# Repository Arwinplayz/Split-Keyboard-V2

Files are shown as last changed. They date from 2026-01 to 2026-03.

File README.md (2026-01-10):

# Split-Keyboard V2

I recently got my PCB from JLCPCB but I realised that I had accidentally inverted the holes for the hotswap sockets. This makes it physically impossible for me to actually assembly it properly. Learning from my failures, I decided to make a V2 which would not only fix the socket problem but also allow me to redo/refine some features. That is I want to add a LiPo battery and change the requirement of having both sides plugged in separately to the PC. I already have the parts to build the keyboard so the grant is only for the PCB (and possibly extra stuff such as LiPo battery, resistors, JST PH connectors, etc)

## Planning

I recently got my PCB from JLCPCB but I realised that I had accidentally inverted the holes for the hotswap sockets. This makes it physically impossible for me to actually assembly it properly. (Awkward placement + overlap with other components)

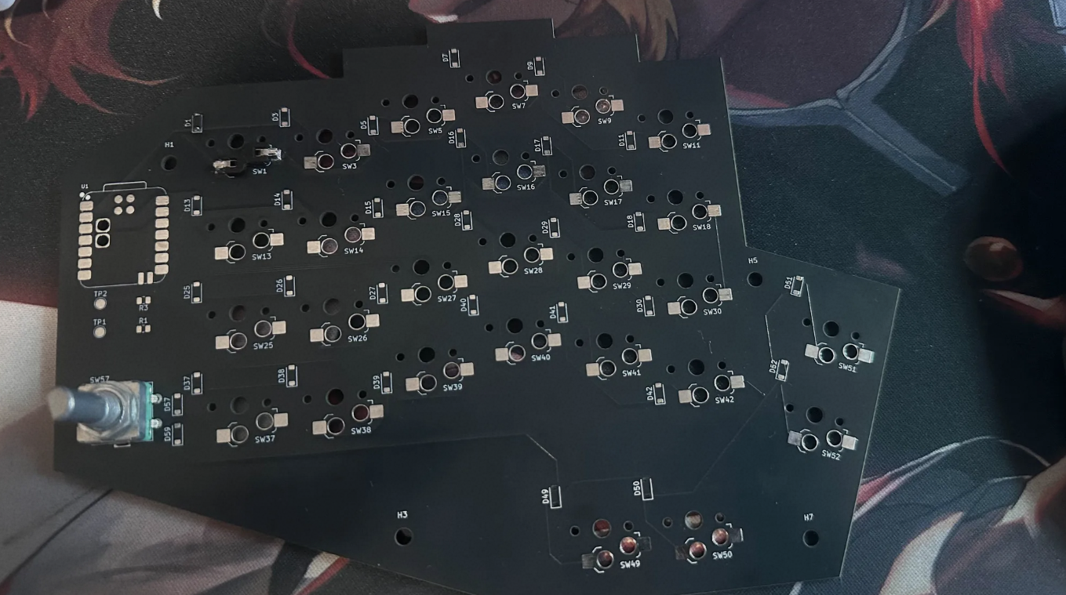
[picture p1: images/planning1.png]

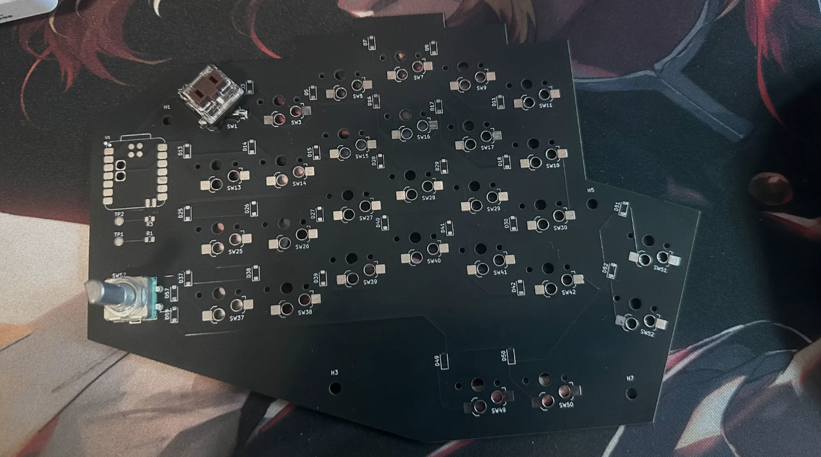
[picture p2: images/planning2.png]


Learning from my failures, I decided to make a V2 which would not only fix the socket problem but also allow me to redo/refine some features. That is I want to add a LiPo battery and change the requirement of having both sides plugged in separately to the PC. I already have the parts to build the keyboard so the grant is only for the PCB (and possibly extra stuff such as LiPo battery, resistors, JST PH connectors, etc)

GOALS:

Fix hotswap socket orientation
Added better connectivity between the split keyboards (Master and Slave RP2040)
Add support for 1s 3.4V LiPo Battery

## Heavily Modified Schematic

So firstly, I realised that to use the master and slave approach, I needed a TRRS which connects the halves via UART. This meant that I needed a UARTTX, UARTRX but all my gpio pins were occupied. After some research I found that the nice!nano v2 was a good choice as it had the same Nordic chip. This allowed for bluetooth connection, a built in linear Li-Po charging circuit which helps avoid clutter. Furthermore, I added a 2 pin JST-PH connector for the Li-Po battery. There is also an RGB LED which will signal green for charged, yellow for 50$, red for low and blue for charging.

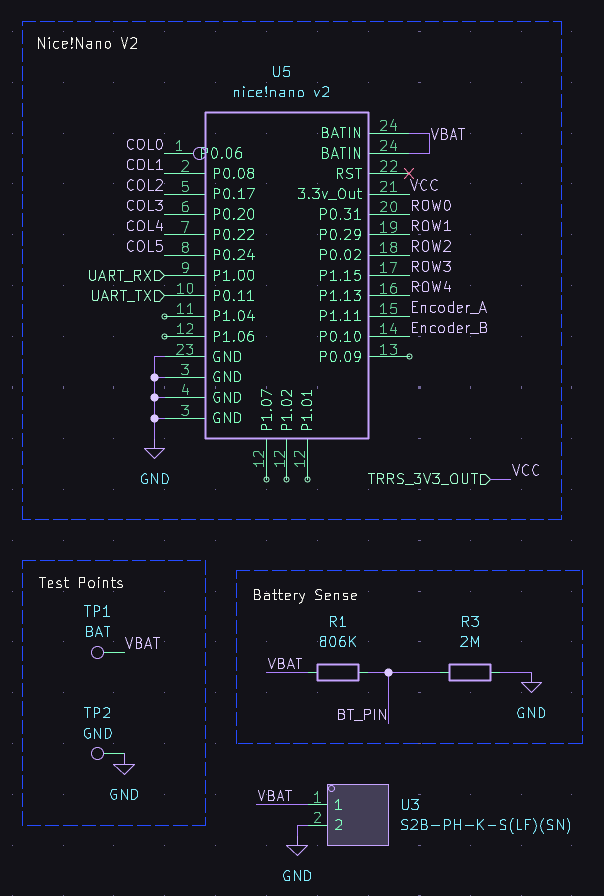
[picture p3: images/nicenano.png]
Nice!nano V2

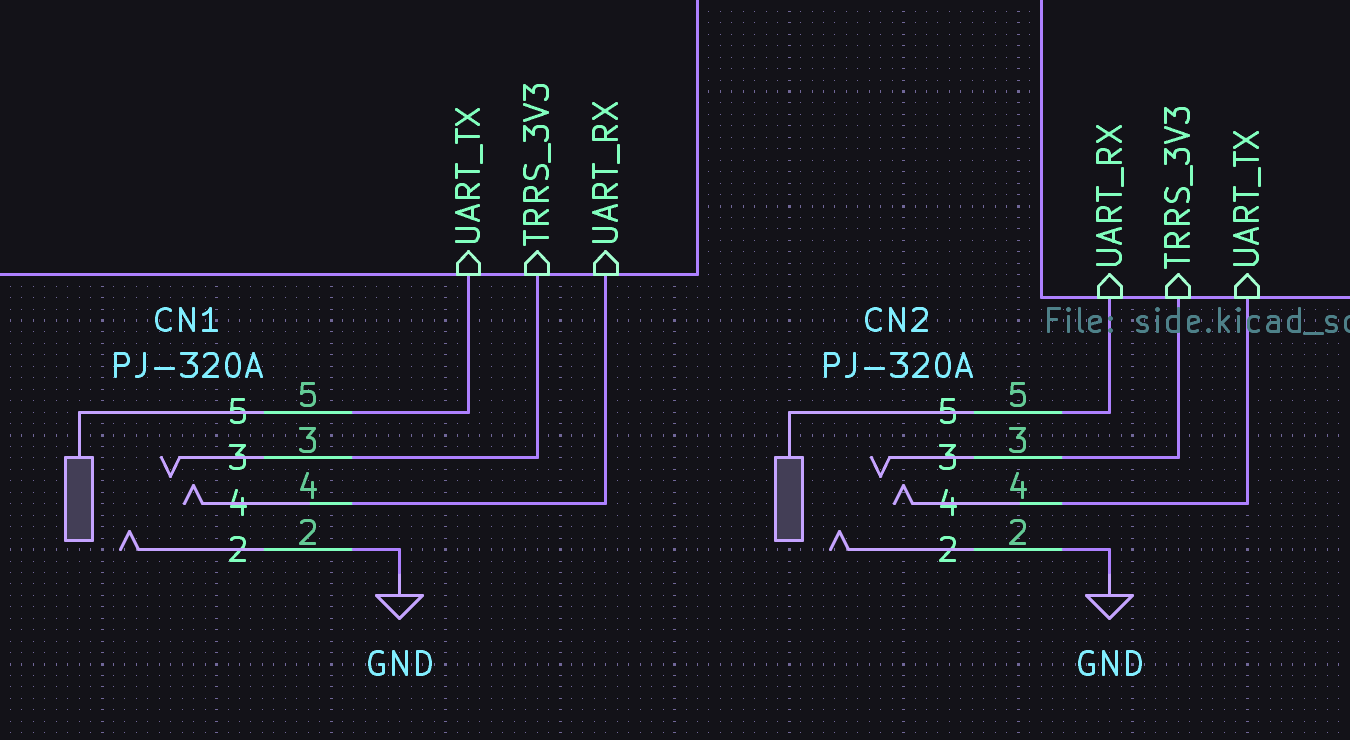
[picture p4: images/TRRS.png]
TRRS

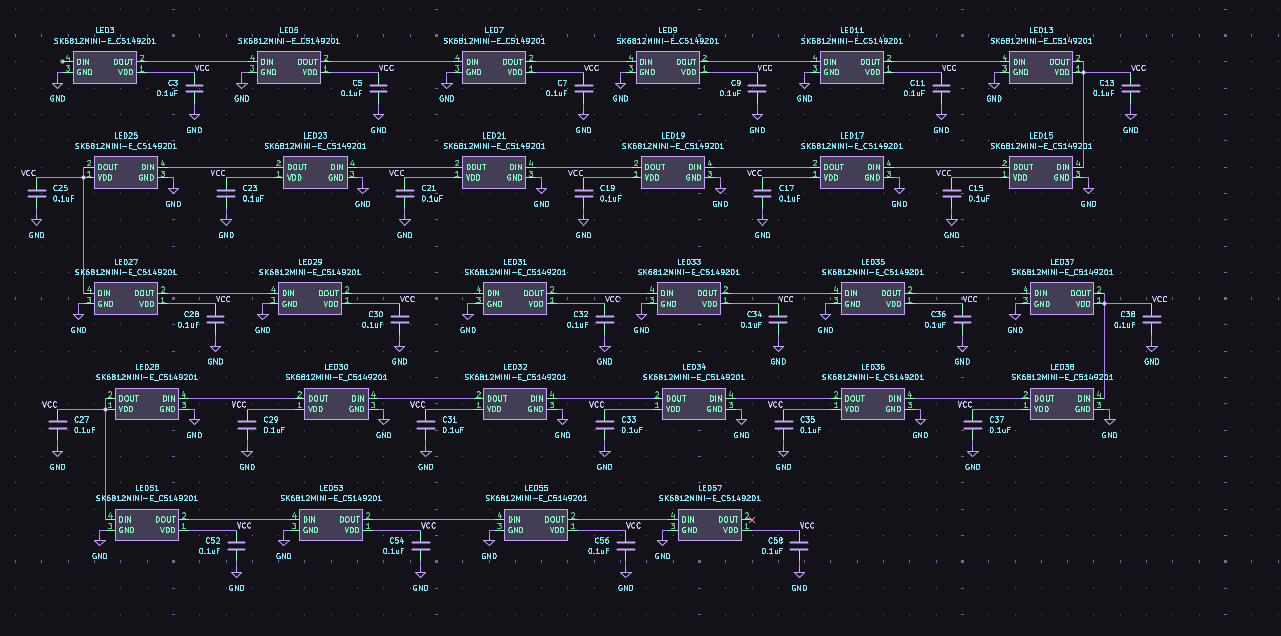
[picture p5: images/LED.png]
LED


## Routed half the PCB

So I managed to route half the PCB now. There were many problems related to footprints as the Nice!Nano doesn't really have a goof publicly available one and so I had to design it myself. Also I added LED lights for every switch and ensured the hotswap sockets were orientated the right way.

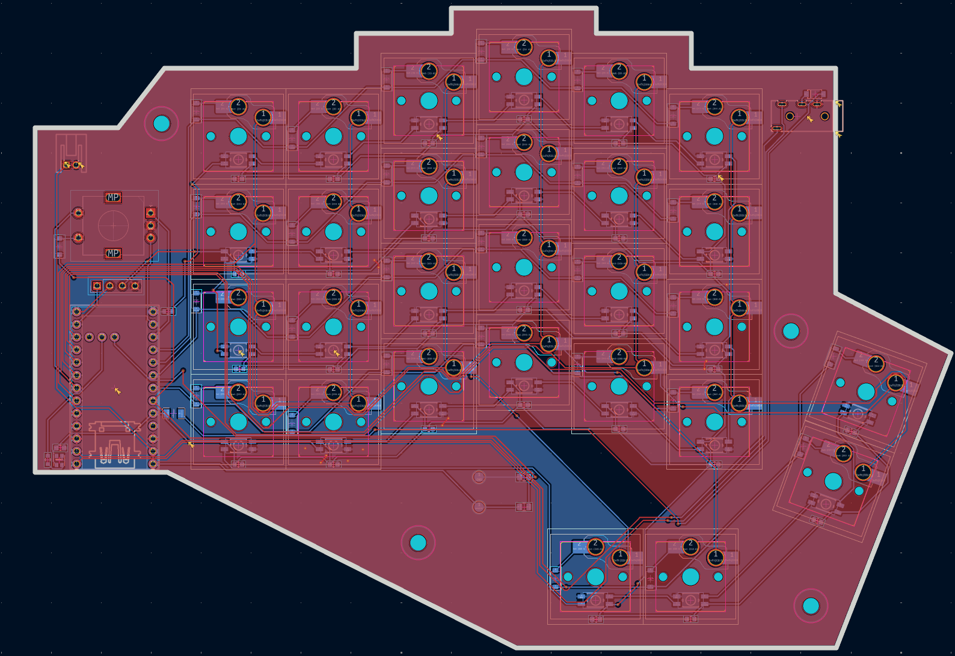
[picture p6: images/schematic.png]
schematic

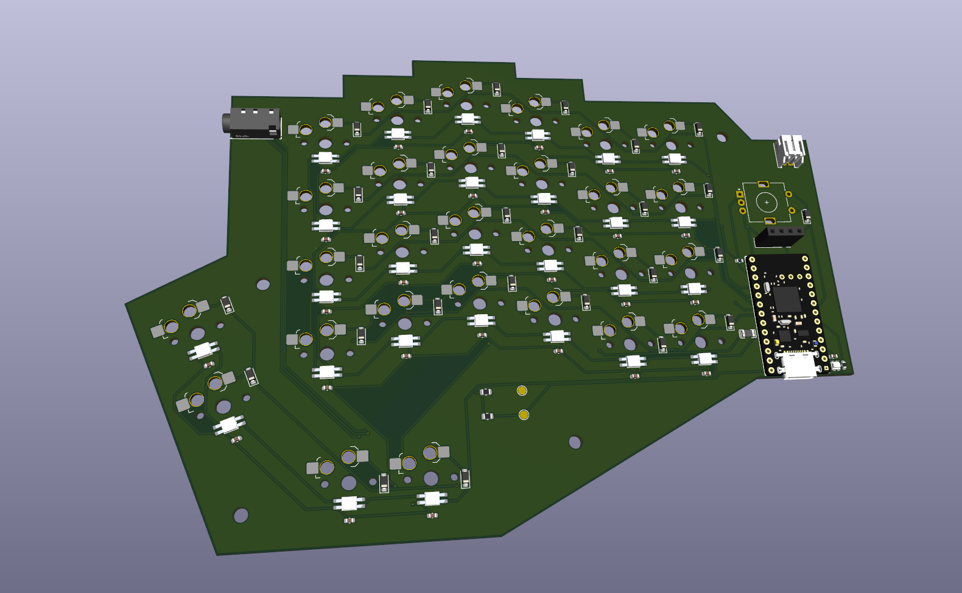
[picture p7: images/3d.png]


## Finished Routing the PCB

So it took me a while to figure out how to mirror the left side. There was no easy way to do so I ended up flipping the edgecut and then redoing all the wiring. There is only 1 error on the ERC which is the left and right side aren't connected by this will get fixed with a TRRC cable.

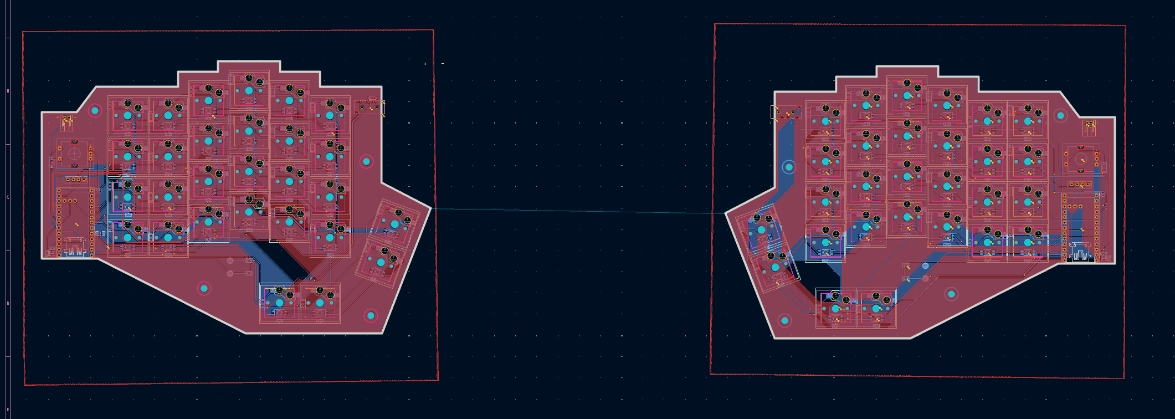
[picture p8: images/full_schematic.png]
schematic

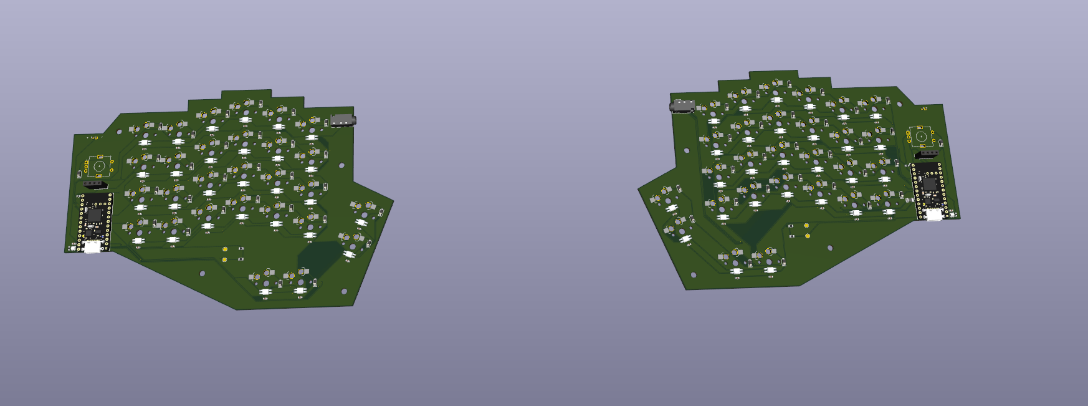
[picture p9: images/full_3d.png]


## Gerber Files

I decided to get PCBA due to the keybaord requiring several LED and Diodes which all require a certain orientation to work properly. A few components require PCBA to be placed. I do have 1 or 2 components which I will hand solder myself to help reduce the costs. The PCB was too large for PCBA so I have to order each half of the PCB seperately.

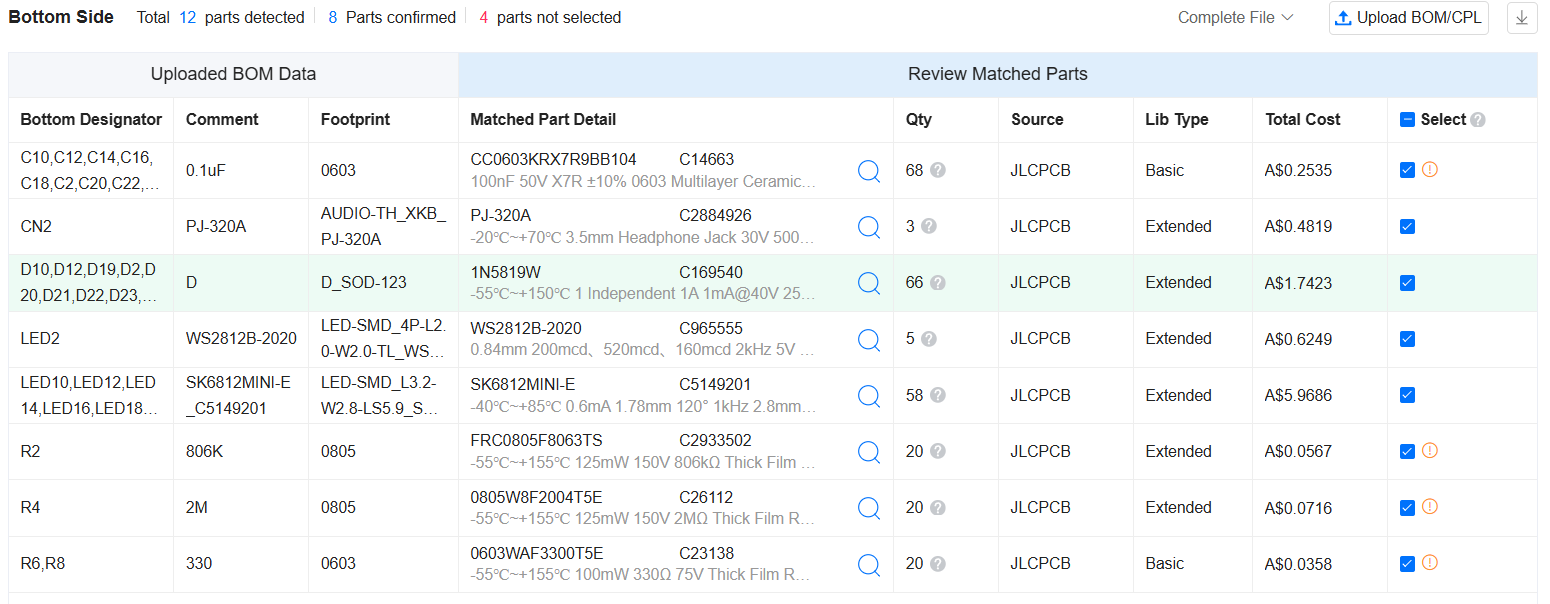
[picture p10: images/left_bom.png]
Left BOM

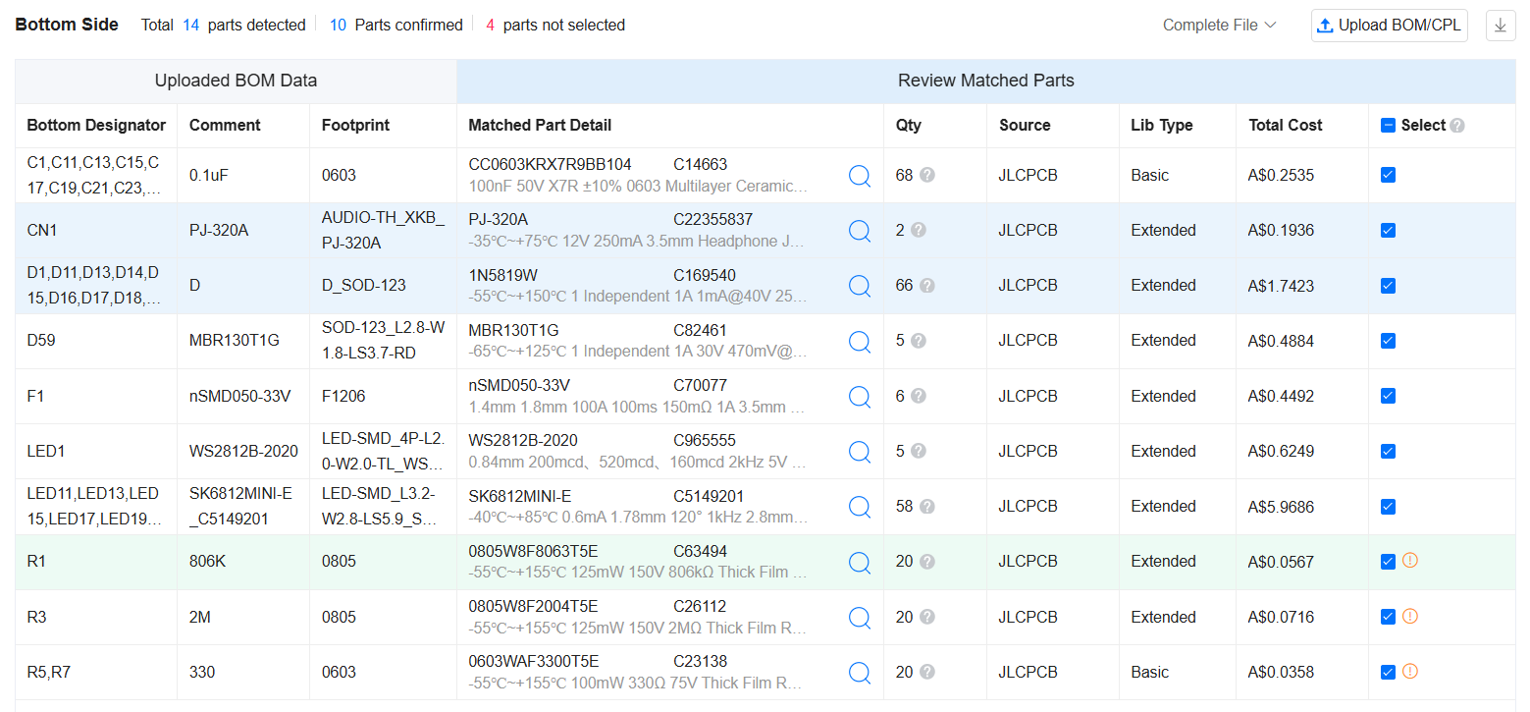
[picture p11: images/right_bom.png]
RIght BOM

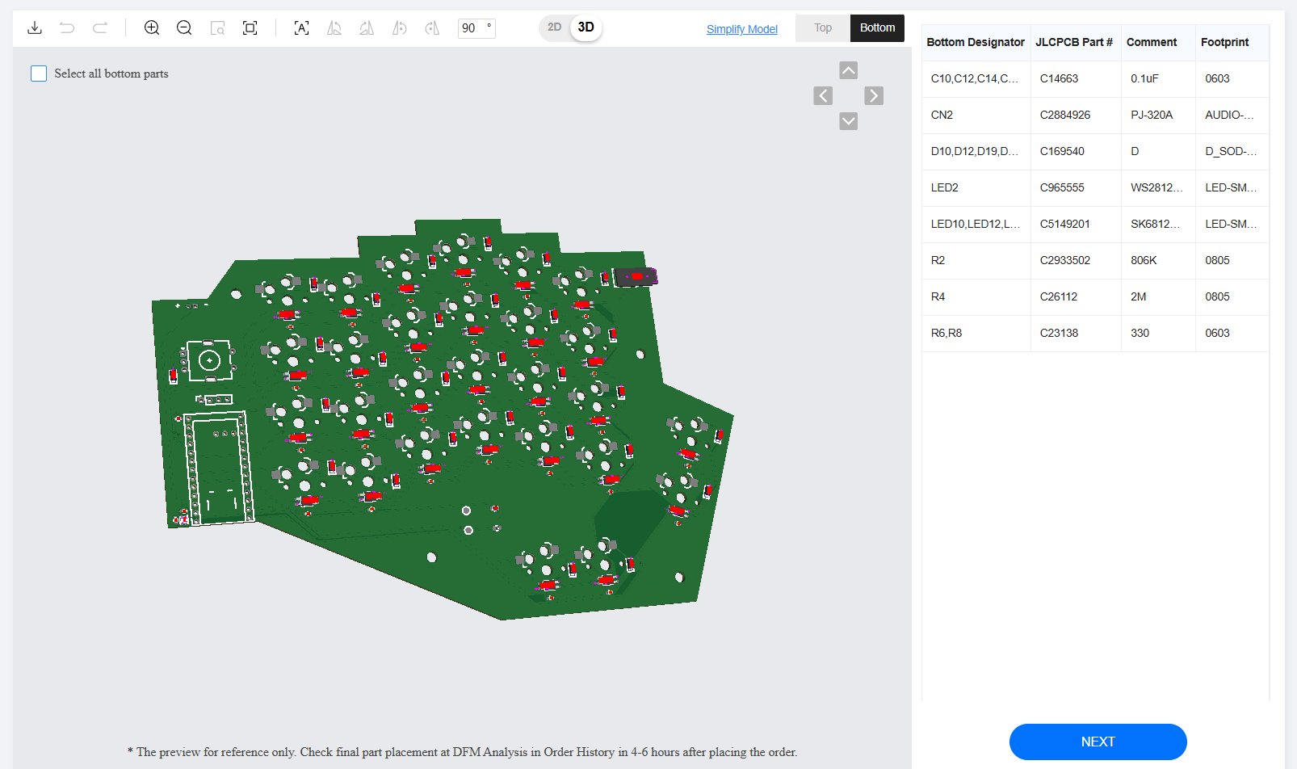
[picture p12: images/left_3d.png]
Left 3D

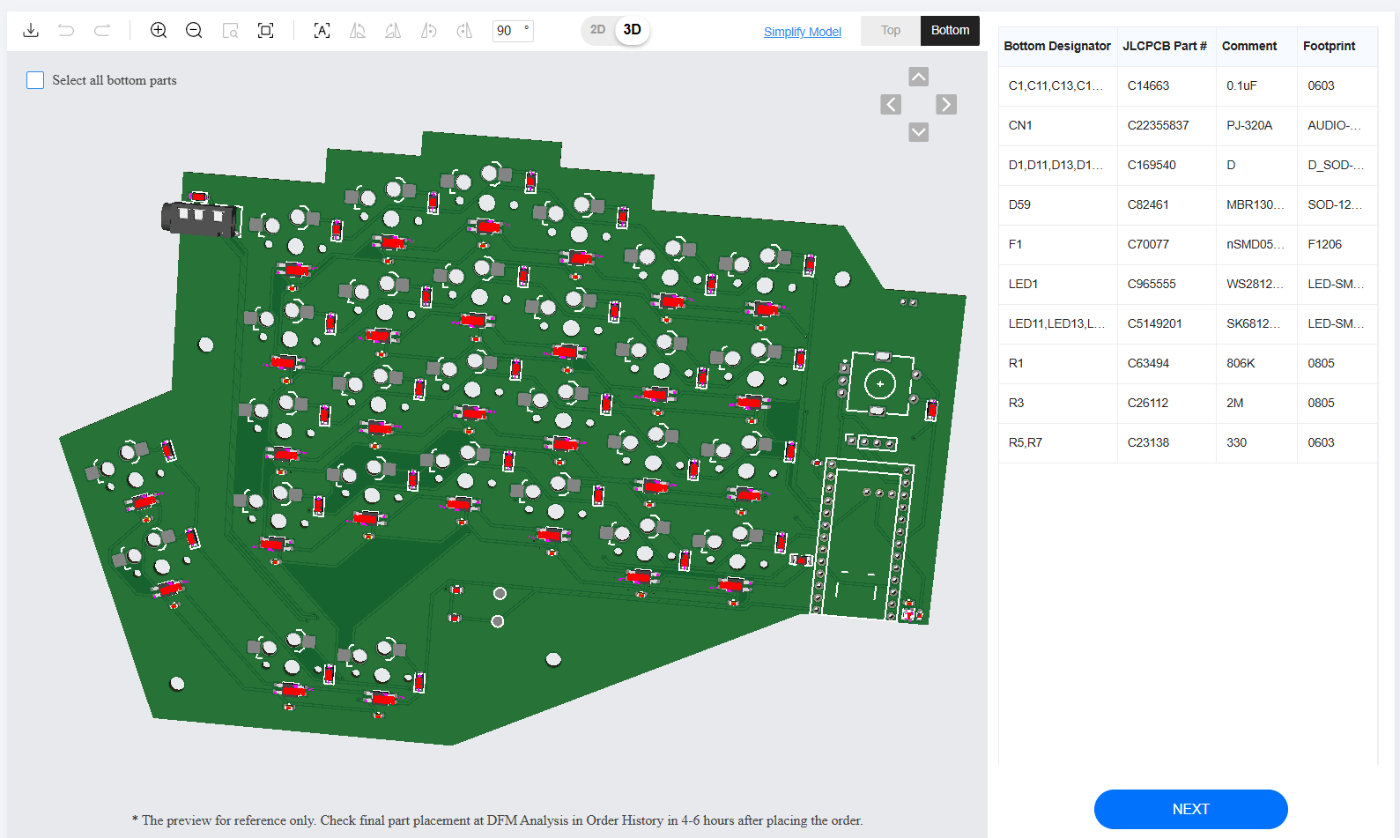
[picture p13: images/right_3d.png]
Right 3D

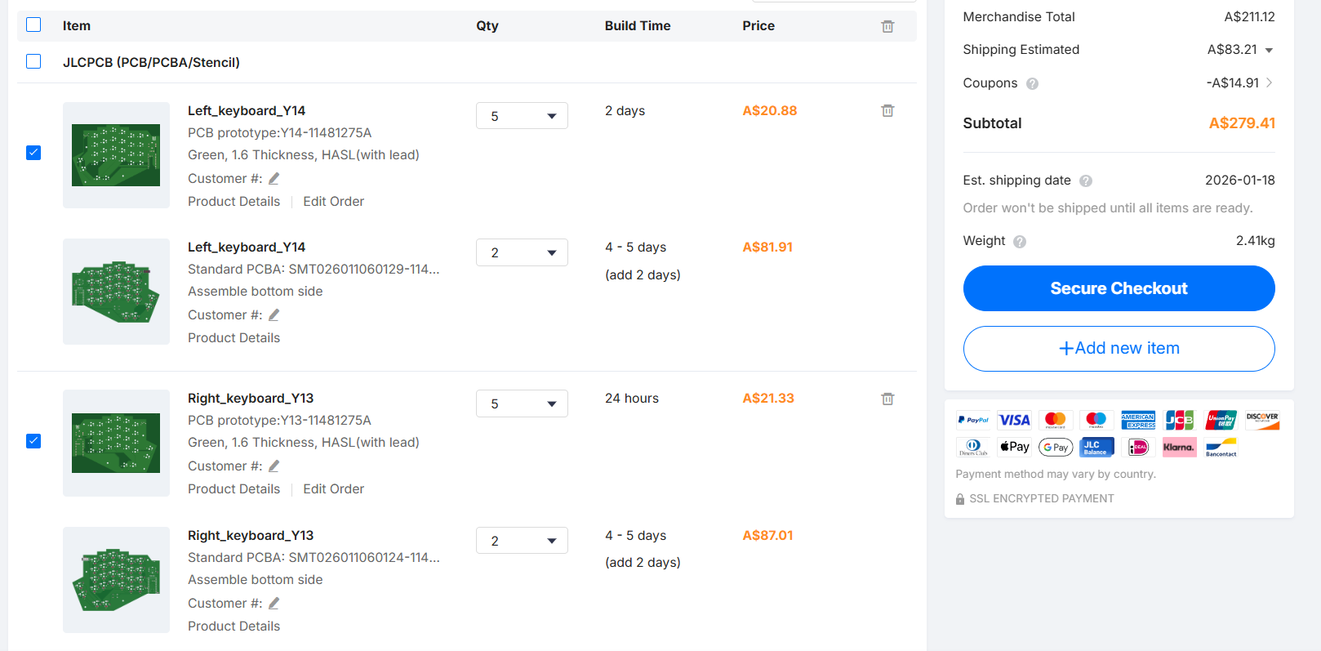
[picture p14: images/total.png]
total

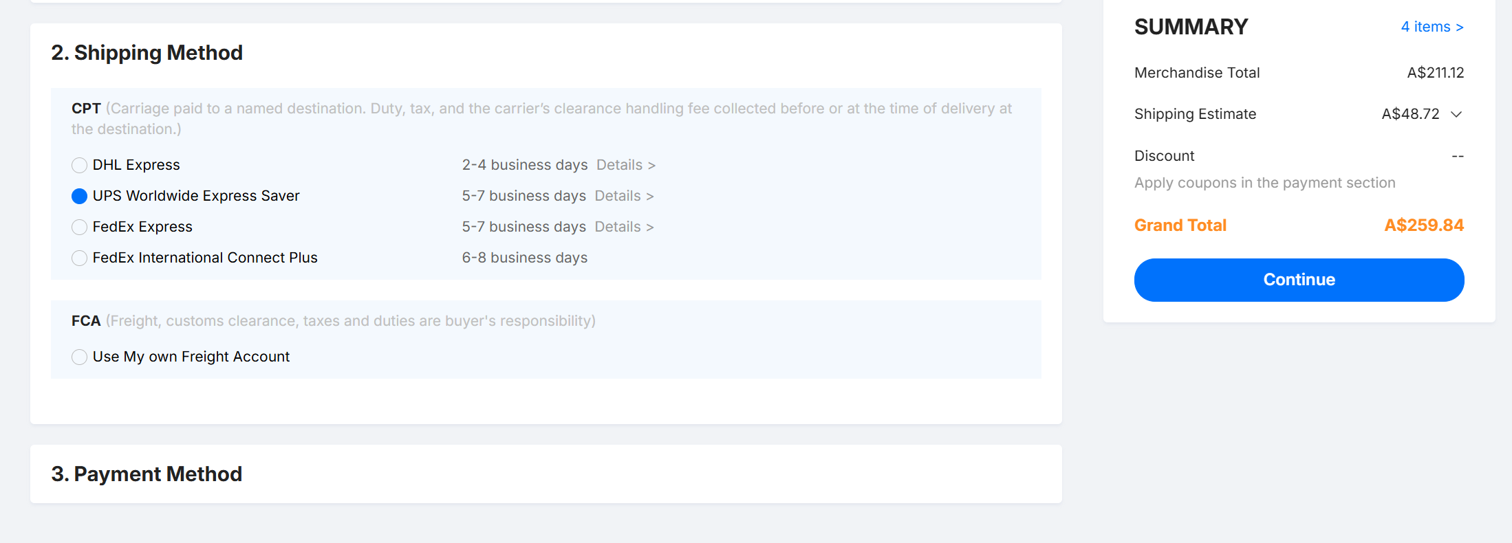
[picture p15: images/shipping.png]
shipping


## BOM

So since I already have most of the components such as rotary encoder, key switches, keycaps, etc, the BOM is prely for the parts I need for the PCB (the extra stuff that I didn't solder from JLC). So the total comes to about 227.98 USD. I really do not know how to make it cheaper as I've sourced everything from the cheapest sites I could find i.e aliexpress.

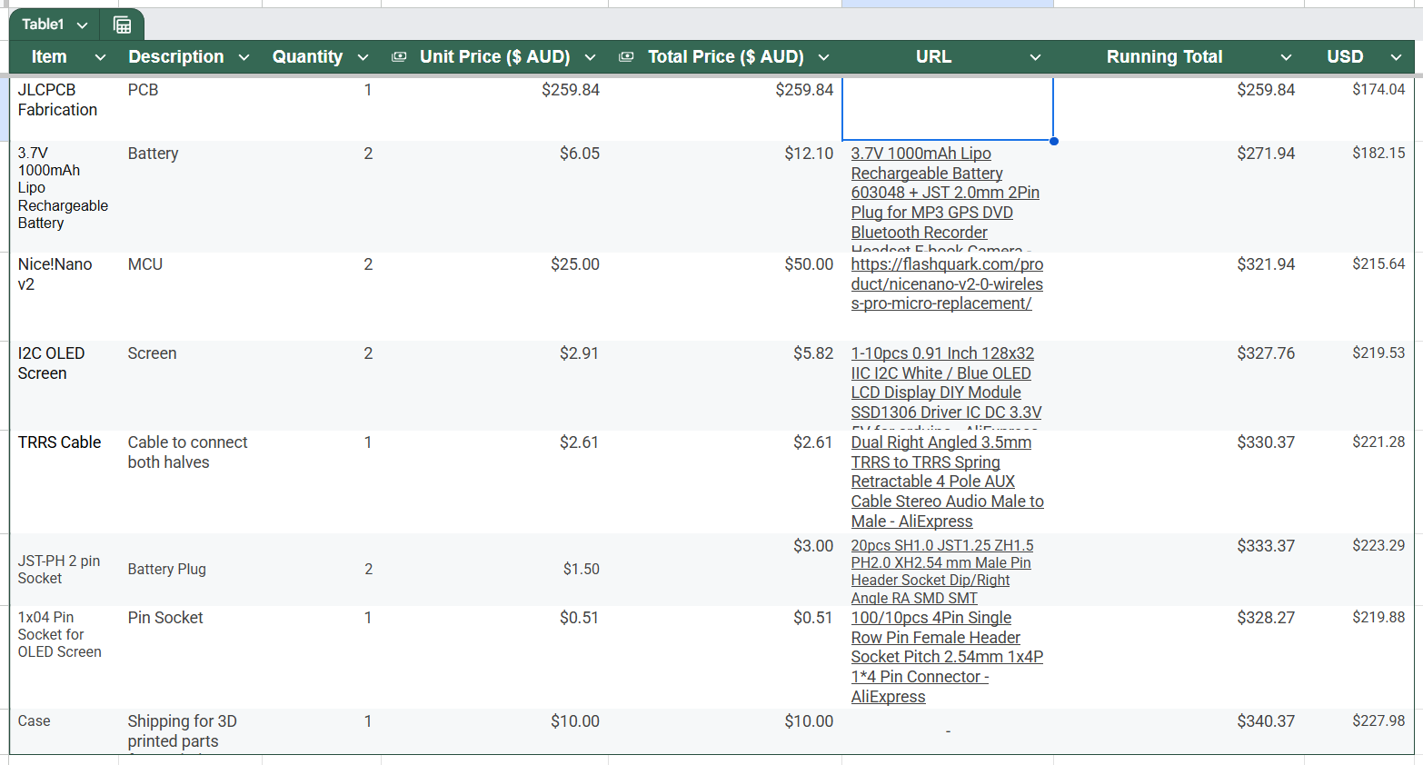
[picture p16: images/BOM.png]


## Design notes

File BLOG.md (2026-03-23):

This was from a V2 of a kyeboard I made online but ultimately wasn't able to build physically. Below I have my journel. I have learn so much about kicad and have definitely learnt from my mistakes. At one point I even went down a rabbit hole of chirality and now I know to make sure they are on the correct side of the PCB.

<!--
  This journal is auto generated by Hack Club Blueprint.
-->

# 1/8/2026 - Planning

_Time spent: 1.0h_

I recently got my PCB from JLCPCB but I realised that I had accidentally inverted the holes for the hotswap sockets. This makes it physically impossible for me to actually assembly it properly. (Awkward placement + overlap with other components)



Learning from my failures, I decided to make a V2 which would not only fix the socket problem but also allow me to redo/refine some features. That is I want to add a LiPo battery and change the requirement of having both sides plugged in separately to the PC. I already have the parts to build the keyboard so the grant is only for the PCB (and possibly extra stuff such as LiPo battery, resistors, JST PH connectors, etc)

GOALS:

- Fix hotswap socket orientation
- Added better connectivity between the split keyboards (Master and Slave RP2040)
- Add support for 1s 3.4V LiPo Battery

# 1/9/2026 12 PM - Heavily Modified Schematic

_Time spent: 2.0h_

So firstly, I realised that to use the master and slave approach, I needed a TRRS which connects the halves via UART. This meant that I needed a UART_TX, UART_RX but all my gpio pins were occupied. After some research I found that the nice!nano v2 was a good choice as it had the same Nordic chip. This allowed for bluetooth connection, a built in linear Li-Po charging circuit which helps avoid clutter. Furthermore, I added a 2 pin JST-PH connector for the Li-Po battery. There is also an RGB LED which will signal green for charged, yellow for 50$, red for low and blue for charging.





# 1/9/2026 6 PM - Routed half the PCB

_Time spent: 4.5h_

So I managed to route half the PCB now. There were many problems related to footprints as the Nice!Nano doesn't really have a goof publicly available one and so I had to design it myself. Also I added LED lights for every switch and ensured the hotswap sockets were orientated the right way.




# 1/10/2026 12 AM - Finished Routing the PCB

_Time spent: 2.0h_

So it took me a while to figure out how to mirror the left side. There was no easy way to do so I ended up flipping the edgecut and then redoing all the wiring. There is only 1 error on the ERC which is the left and right side aren't connected by this will get fixed with a TRRC cable.



# 1/10/2026 2:07 PM - Gerber Files

_Time spent: 0.5h_

I decided to get PCBA due to the keybaord requiring several LED and Diodes which all require a certain orientation to work properly. A few components require PCBA to be placed. I do have 1 or 2 components which I will hand solder myself to help reduce the costs. The PCB was too large for PCBA so I have to order each half of the PCB seperately.






P.S UPS Worldwide Express Saver was the cheapest shipping, If overall the price is too high for funding, i am willing to pay for some things.

# 1/10/2026 2:11 PM - BOM

_Time spent: 1.0h_

So since I already have most of the components such as rotary encoder, key switches, keycaps, etc, the BOM is prely for the parts I need for the PCB (the extra stuff that I didn't solder from JLC). So the total comes to about 227.98 USD. I really do not know how to make it cheaper as I've sourced everything from the cheapest sites I could find i.e aliexpress.


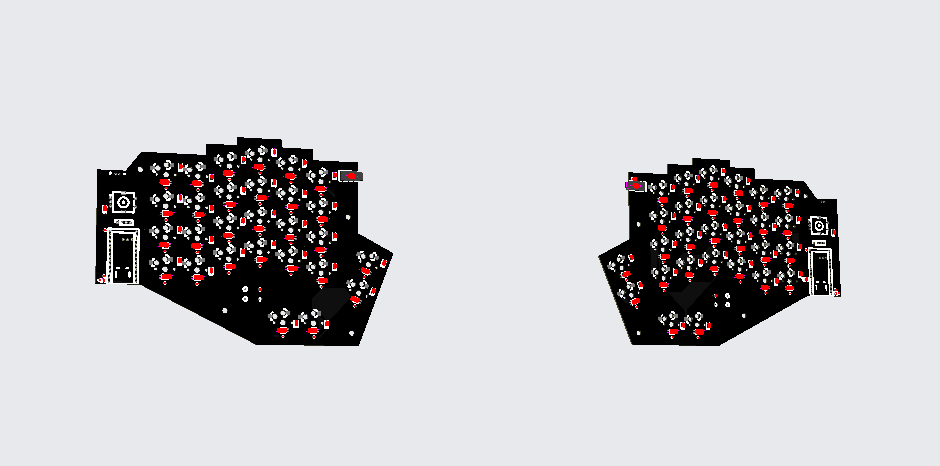
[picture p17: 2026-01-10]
images/Screenshot 2026-01-10 004802.png

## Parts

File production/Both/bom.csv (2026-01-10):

Designator | Footprint | Quantity | Value | LCSC Part #
C1, C10, C11, C12, C13, C14, C15, C16, C17, C18, C19, C2, C20, C21, C22, C23, C24, C25, C26, C27, C28, C29, C3, C30, C31, C32, C33, C34, C35, C36, C37, C38, C39, C4, C40, C41, C42, C43, C44, C45, C46, C47, C48, C49, C5, C50, C52, C54, C56, C58, C6, C64, C66, C68, C7, C70, C8, C9 | 0603 | 58 | 0.1uF
CN1, CN2 | AUDIO-TH_XKB_PJ-320A | 2 | PJ-320A | C2884926
D1, D10, D11, D12, D13, D14, D15, D16, D17, D18, D19, D2, D20, D21, D22, D23, D24, D25, D26, D27, D28, D29, D3, D30, D31, D32, D33, D34, D35, D36, D37, D38, D39, D4, D40, D41, D42, D43, D44, D45, D46, D47, D48, D49, D5, D50, D51, D52, D53, D54, D55, D56, D57, D58, D6, D7, D8, D9 | D_SOD-123 | 58 | D
D59 | SOD-123_L2.8-W1.8-LS3.7-RD | 1 | MBR130T1G | C82461
F1 | F1206 | 1 | nSMD050-33V | C70077
J1, J2 | PinSocket_1x04_P2.54mm_Vertical | 2 | Conn_01x04_Socket
LED1, LED2 | LED-SMD_4P-L2.0-W2.0-TL_WS2812B-2020 | 2 | WS2812B-2020 | C965555
LED10, LED11, LED12, LED13, LED14, LED15, LED16, LED17, LED18, LED19, LED20, LED21, LED22, LED23, LED24, LED25, LED26, LED27, LED28, LED29, LED3, LED30, LED31, LED32, LED33, LED34, LED35, LED36, LED37, LED38, LED39, LED4, LED40, LED41, LED42, LED43, LED44, LED45, LED46, LED47, LED48, LED49, LED5, LED50, LED51, LED53, LED55, LED57, LED6, LED63, LED65, LED67, LED69, LED7, LED8, LED9 | LED-SMD_L3.2-W2.8-LS5.9_SK6812MINI-E | 56 | SK6812MINI-E_C5149201 | C5149201
R1, R2 | 0805 | 2 | 806K
R3, R4 | 0805 | 2 | 2M
R5, R6, R7, R8 | 0603 | 4 | 330
SW1, SW10, SW11, SW12, SW13, SW14, SW15, SW16, SW17, SW18, SW19, SW2, SW20, SW21, SW22, SW23, SW24, SW25, SW26, SW27, SW28, SW29, SW3, SW30, SW31, SW32, SW33, SW34, SW35, SW36, SW37, SW38, SW39, SW4, SW40, SW41, SW42, SW43, SW44, SW45, SW46, SW47, SW48, SW49, SW5, SW50, SW51, SW52, SW53, SW54, SW55, SW56, SW6, SW7, SW8, SW9 | SW_choc_v1_HS_CPG135001S30_1u | 56 | SW_Push
SW57, SW58 | RotaryEncoder_Alps_EC11E-Switch_Vertical_H20mm | 2 | RotaryEncoder_Switch
TP1, TP3 | TestPoint_Pad_D2.0mm | 2 | BAT
TP2, TP4 | TestPoint_Pad_D2.0mm | 2 | GND
U3, U4 | CONN-TH_S2B-PH-K-S-LF-SN | 2 | S2B-PH-K-S(LF)(SN) | C173752
U5, U6 | NICE!NANO V2_2 | 2 | nice!nano v2

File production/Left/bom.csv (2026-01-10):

Designator | Footprint | Quantity | Value | LCSC Part #
C10, C12, C14, C16, C18, C2, C20, C22, C24, C26, C39, C4, C40, C41, C42, C43, C44, C45, C46, C47, C48, C49, C50, C6, C64, C66, C68, C70, C8 | 0603 | 29 | 0.1uF
CN2 | AUDIO-TH_XKB_PJ-320A | 1 | PJ-320A | C2884926
D10, D12, D19, D2, D20, D21, D22, D23, D24, D31, D32, D33, D34, D35, D36, D4, D43, D44, D45, D46, D47, D48, D53, D54, D55, D56, D58, D6, D8 | D_SOD-123 | 29 | D
J2 | PinSocket_1x04_P2.54mm_Vertical | 1 | Conn_01x04_Socket
LED10, LED12, LED14, LED16, LED18, LED20, LED22, LED24, LED26, LED39, LED4, LED40, LED41, LED42, LED43, LED44, LED45, LED46, LED47, LED48, LED49, LED50, LED6, LED63, LED65, LED67, LED69, LED8 | LED-SMD_L3.2-W2.8-LS5.9_SK6812MINI-E | 28 | SK6812MINI-E_C5149201 | C5149201
LED2 | LED-SMD_4P-L2.0-W2.0-TL_WS2812B-2020 | 1 | WS2812B-2020 | C965555
R2 | 0805 | 1 | 806K
R4 | 0805 | 1 | 2M
R6, R8 | 0603 | 2 | 330
SW10, SW12, SW19, SW2, SW20, SW21, SW22, SW23, SW24, SW31, SW32, SW33, SW34, SW35, SW36, SW4, SW43, SW44, SW45, SW46, SW47, SW48, SW53, SW54, SW55, SW56, SW6, SW8 | SW_choc_v1_HS_CPG135001S30_1u | 28 | SW_Push
SW58 | RotaryEncoder_Alps_EC11E-Switch_Vertical_H20mm | 1 | RotaryEncoder_Switch
TP3 | TestPoint_Pad_D2.0mm | 1 | BAT
TP4 | TestPoint_Pad_D2.0mm | 1 | GND
U4 | CONN-TH_S2B-PH-K-S-LF-SN | 1 | S2B-PH-K-S(LF)(SN) | C173752
U6 | NICE!NANO V2_2 | 1 | nice!nano v2

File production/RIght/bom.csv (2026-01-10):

Designator | Footprint | Quantity | Value | LCSC Part #
C1, C11, C13, C15, C17, C19, C21, C23, C25, C27, C28, C29, C3, C30, C31, C32, C33, C34, C35, C36, C37, C38, C5, C52, C54, C56, C58, C7, C9 | 0603 | 29 | 0.1uF
CN1 | AUDIO-TH_XKB_PJ-320A | 1 | PJ-320A | C2884926
D1, D11, D13, D14, D15, D16, D17, D18, D25, D26, D27, D28, D29, D3, D30, D37, D38, D39, D40, D41, D42, D49, D5, D50, D51, D52, D57, D7, D9 | D_SOD-123 | 29 | D
D59 | SOD-123_L2.8-W1.8-LS3.7-RD | 1 | MBR130T1G | C82461
F1 | F1206 | 1 | nSMD050-33V | C70077
J1 | PinSocket_1x04_P2.54mm_Vertical | 1 | Conn_01x04_Socket
LED1 | LED-SMD_4P-L2.0-W2.0-TL_WS2812B-2020 | 1 | WS2812B-2020 | C965555
LED11, LED13, LED15, LED17, LED19, LED21, LED23, LED25, LED27, LED28, LED29, LED3, LED30, LED31, LED32, LED33, LED34, LED35, LED36, LED37, LED38, LED5, LED51, LED53, LED55, LED57, LED7, LED9 | LED-SMD_L3.2-W2.8-LS5.9_SK6812MINI-E | 28 | SK6812MINI-E_C5149201 | C5149201
R1 | 0805 | 1 | 806K
R3 | 0805 | 1 | 2M
R5, R7 | 0603 | 2 | 330
SW1, SW11, SW13, SW14, SW15, SW16, SW17, SW18, SW25, SW26, SW27, SW28, SW29, SW3, SW30, SW37, SW38, SW39, SW40, SW41, SW42, SW49, SW5, SW50, SW51, SW52, SW7, SW9 | SW_choc_v1_HS_CPG135001S30_1u | 28 | SW_Push
SW57 | RotaryEncoder_Alps_EC11E-Switch_Vertical_H20mm | 1 | RotaryEncoder_Switch
TP1 | TestPoint_Pad_D2.0mm | 1 | BAT
TP2 | TestPoint_Pad_D2.0mm | 1 | GND
U3 | CONN-TH_S2B-PH-K-S-LF-SN | 1 | S2B-PH-K-S(LF)(SN) | C173752
U5 | NICE!NANO V2_2 | 1 | nice!nano v2

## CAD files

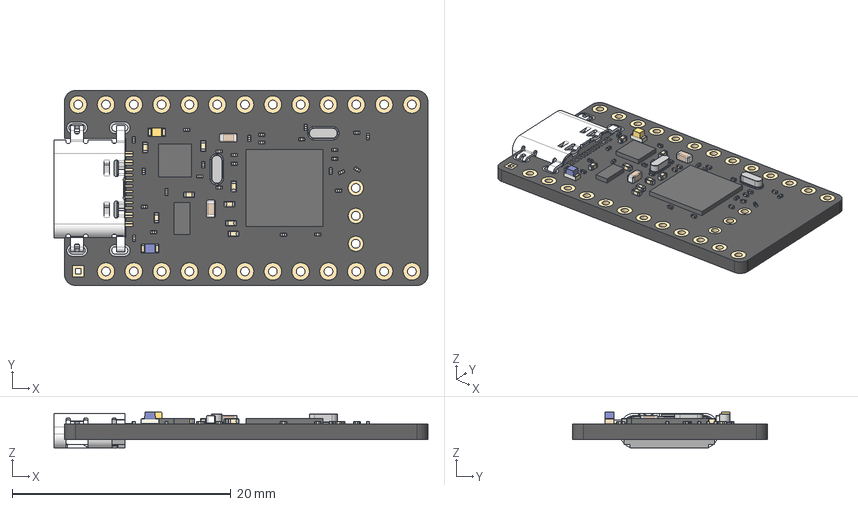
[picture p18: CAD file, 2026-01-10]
CAD/nice!nano v2.step
34.2 x 17.8 x 3.28 mm
nice!nano v1.0
SSOP16
LED_0603_1608Metric_ON
LED_0603_1608Metric_ON_1
Crystal Oscillator
Crystal Oscillator_1
usb4520-03-0-a_1
C0201 x 21
C0402 x 8
C0201_1 x 7

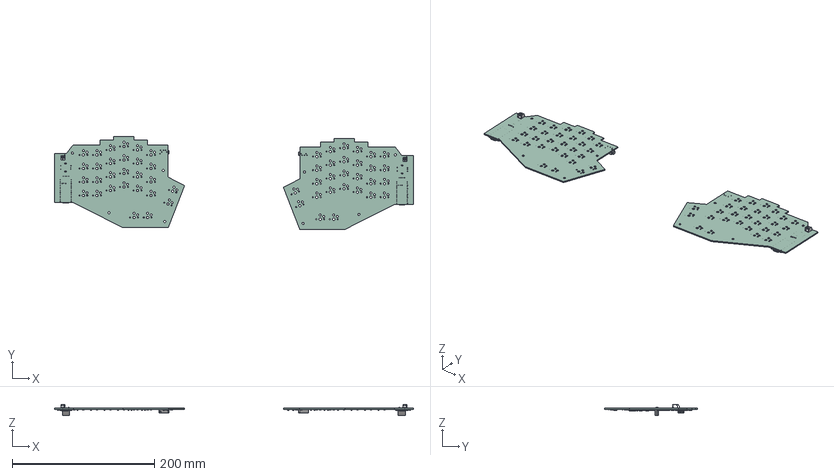
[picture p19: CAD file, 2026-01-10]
PCB/Split keyboard.step
505.4 x 130.4 x 15.2 mm
CONN-TH_HR-PH2.0-WI-2P x 2
LED-SMD_L3.2-W2.8-LS5.9_SK6812MINI-E x 56
C_0603_1608Metric x 58
D_SOD-123 x 58
R_0805_2012Metric x 4
AUDIO-TH_XKB_PJ-320A x 2
SOD-123_L2.8-W1.8-LS3.7-RD
PinSocket_1x04_P2.54mm_Vertical x 2
LED-SMD_4P-L2.0-W2.0-H0.8-TL_WS2812B-2020 x 2
F1206_L3.2-W1.7-H0.6
R_0603_1608Metric x 4
nice!nano v1.0 x 2
mcu-chip-ic-2set-leg v1 x 2
LED_0603_1608Metric_ON v1 x 2
LED_0603_1608Metric_ON v1(Mirror) x 2
Crystal Oscillator v3 x 2
Crystal Oscillator v3 (1) x 2
usb4520-03-0-a v1 x 2
C0201 v1 x 56
C0402 v1 x 16
0603 v1 x 4
Split keyboard_PCB_1
Split keyboard_PCB_2

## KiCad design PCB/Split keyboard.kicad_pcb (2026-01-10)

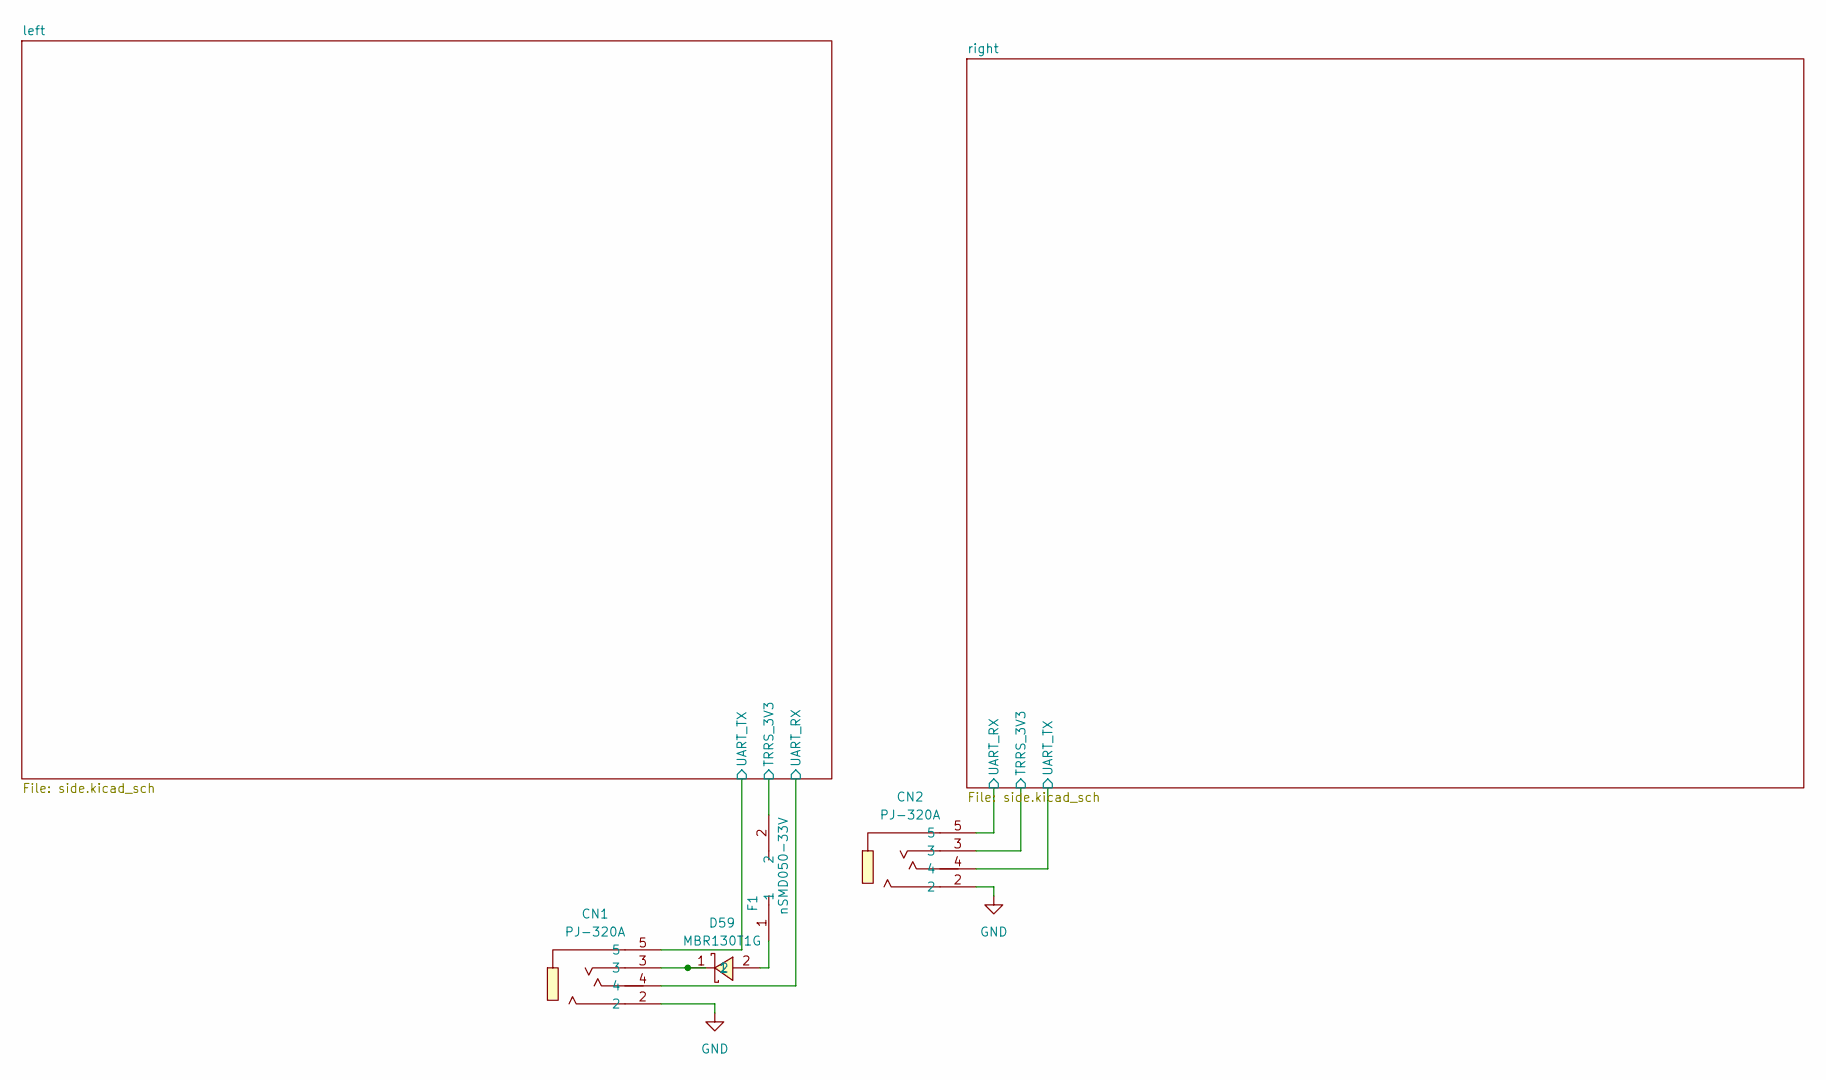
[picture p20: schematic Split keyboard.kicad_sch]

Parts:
CN1, CN2: PJ-320A; AUDIO-TH_XKB_PJ-320A; LCSC Part C2884926
D59: MBR130T1G; SOD-123_L2.8-W1.8-LS3.7-RD; LCSC Part C82461
F1: nSMD050-33V; F1206; LCSC Part C70077

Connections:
/left/UART_RX: CN1.4; also elsewhere on the board
/left/UART_TX: CN1.5; also elsewhere on the board
/left/VCC: F1.2; also elsewhere on the board
/right/UART_RX: CN2.5; also elsewhere on the board
/right/UART_TX: CN2.4; also elsewhere on the board
/right/VCC: CN2.3; also elsewhere on the board
GND: CN1.2, CN2.2; also elsewhere on the board
unnamed: CN1.3, D59.1
unnamed: D59.2, F1.1

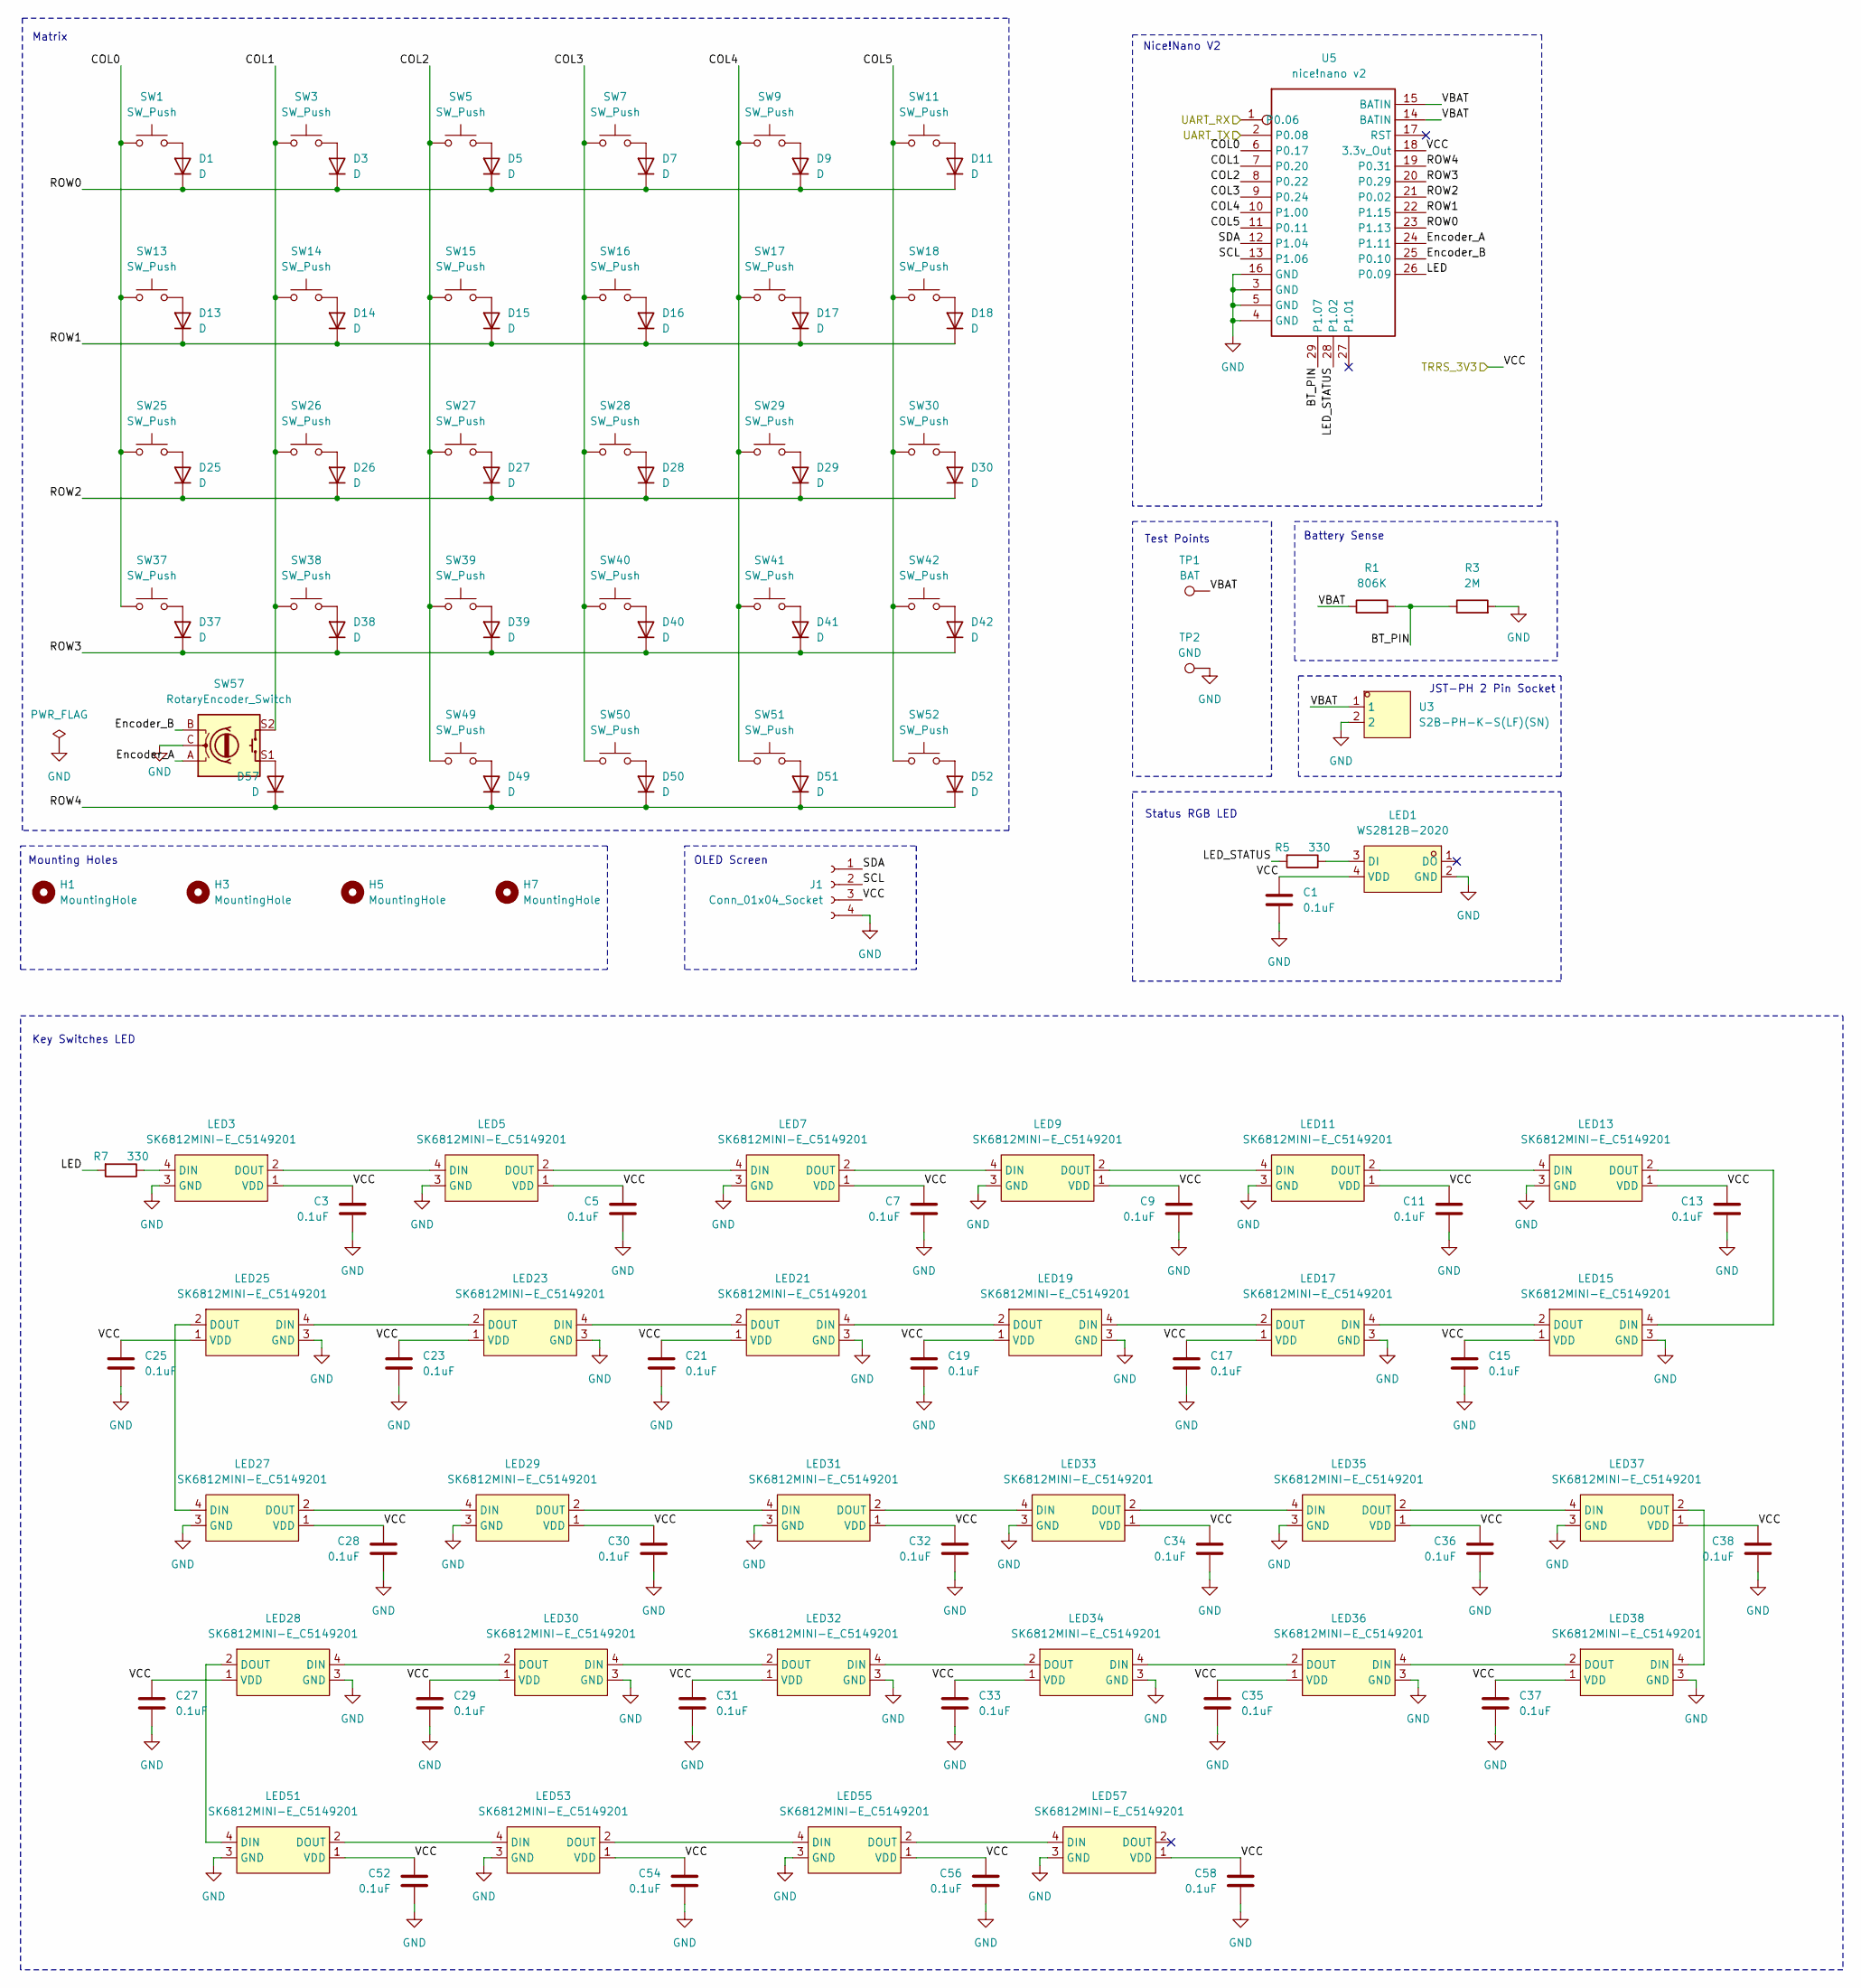
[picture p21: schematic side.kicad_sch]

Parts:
C1, C3, C5, C7, C9, C11, C13, C15, C17, C19, C21, C23, C25, C27, C28, C29, C30, C31, C32, C33, C34, C35, C36, C37, C38, C52, C54, C56, C58: 0.1uF; C_0603_1608Metric
D1, D3, D5, D7, D9, D11, D13, D14, D15, D16, D17, D18, D25, D26, D27, D28, D29, D30, D37, D38, D39, D40, D41, D42, D49, D50, D51, D52, D57: D; D_SOD-123
H1, H3, H5, H7: MountingHole; MountingHole_3.2mm_M3
J1: Conn_01x04_Socket; PinSocket_1x04_P2.54mm_Vertical
LED1: WS2812B-2020; LED-SMD_4P-L2.0-W2.0-TL_WS2812B-2020; LCSC Part C965555
LED3, LED5, LED7, LED9, LED11, LED13, LED15, LED17, LED19, LED21, LED23, LED25, LED27, LED28, LED29, LED30, LED31, LED32, LED33, LED34, LED35, LED36, LED37, LED38, LED51, LED53, LED55, LED57: SK6812MINI-E_C5149201; LED-SMD_L3.2-W2.8-LS5.9_SK6812MINI-E; LCSC Part C5149201
R1: 806K; R_0805_2012Metric
R3: 2M; R_0805_2012Metric
R5, R7: 330; R_0603_1608Metric
SW1, SW3, SW5, SW7, SW9, SW11, SW13, SW14, SW15, SW16, SW17, SW18, SW25, SW26, SW27, SW28, SW29, SW30, SW37, SW38, SW39, SW40, SW41, SW42, SW49, SW50, SW51, SW52: SW_Push; SW_choc_v1_HS_CPG135001S30_1u
SW57: RotaryEncoder_Switch; RotaryEncoder_Alps_EC11E-Switch_Vertical_H20mm
TP1: BAT; TestPoint_Pad_D2.0mm
TP2: GND; TestPoint_Pad_D2.0mm
U3: S2B-PH-K-S(LF)(SN); CONN-TH_S2B-PH-K-S-LF-SN; LCSC Part C173752
U5: nice!nano v2; NICE!NANO V2_2

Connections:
/left/BT_PIN: R1.2, R3.1, U5.29 (P1.07)
/left/COL0: SW1.1, SW13.1, SW25.1, SW37.1, U5.6 (P0.17)
/left/COL1: SW3.1, SW14.1, SW26.1, SW38.1, SW57.S2, U5.7 (P0.20)
/left/COL2: SW5.1, SW15.1, SW27.1, SW39.1, SW49.1, U5.8 (P0.22)
/left/COL3: SW7.1, SW16.1, SW28.1, SW40.1, SW50.1, U5.9 (P0.24)
/left/COL4: SW9.1, SW17.1, SW29.1, SW41.1, SW51.1, U5.10 (P1.00)
/left/COL5: SW11.1, SW18.1, SW30.1, SW42.1, SW52.1, U5.11 (P0.11)
/left/Encoder_A: SW57.A, U5.24 (P1.11)
/left/Encoder_B: SW57.B, U5.25 (P0.10)
/left/LED: R7.2, U5.26 (P0.09)
/left/LED_STATUS: R5.2, U5.28 (P1.02)
/left/ROW0: D1.1 (K), D3.1 (K), D5.1 (K), D7.1 (K), D9.1 (K), D11.1 (K), U5.23 (P1.13)
/left/ROW1: D13.1 (K), D14.1 (K), D15.1 (K), D16.1 (K), D17.1 (K), D18.1 (K), U5.22 (P1.15)
/left/ROW2: D25.1 (K), D26.1 (K), D27.1 (K), D28.1 (K), D29.1 (K), D30.1 (K), U5.21 (P0.02)
/left/ROW3: D37.1 (K), D38.1 (K), D39.1 (K), D40.1 (K), D41.1 (K), D42.1 (K), U5.20 (P0.29)
/left/ROW4: D49.1 (K), D50.1 (K), D51.1 (K), D52.1 (K), D57.1 (K), U5.19 (P0.31)
/left/SCL: J1.2, U5.13 (P1.06)
/left/SDA: J1.1, U5.12 (P1.04)
/left/UART_RX: U5.1 (P0.06); also elsewhere on the board
/left/UART_TX: U5.2 (P0.08); also elsewhere on the board
/left/VBAT: R1.1, TP1.1, U3.1, U5.14 (BATIN), U5.15 (BATIN)
/left/VCC: C1.1, C3.1, C5.1, C7.1, C9.1, C11.1, C13.1, C15.1, C17.1, C19.1, C21.1, C23.1, C25.1, C27.1, C28.1, C29.1, C30.1, C31.1, C32.1, C33.1, C34.1, C35.1, C36.1, C37.1, C38.1, C52.1, C54.1, C56.1, C58.1, J1.3, LED1.4 (VDD), LED3.1 (VDD), LED5.1 (VDD), LED7.1 (VDD), LED9.1 (VDD), LED11.1 (VDD), LED13.1 (VDD), LED15.1 (VDD), LED17.1 (VDD), LED19.1 (VDD), LED21.1 (VDD), LED23.1 (VDD), LED25.1 (VDD), LED27.1 (VDD), LED28.1 (VDD), LED29.1 (VDD), LED30.1 (VDD), LED31.1 (VDD), LED32.1 (VDD), LED33.1 (VDD), LED34.1 (VDD), LED35.1 (VDD), LED36.1 (VDD), LED37.1 (VDD), LED38.1 (VDD), LED51.1 (VDD), LED53.1 (VDD), LED55.1 (VDD), LED57.1 (VDD), U5.18 (3.3v_Out); also elsewhere on the board
GND: C1.2, C3.2, C5.2, C7.2, C9.2, C11.2, C13.2, C15.2, C17.2, C19.2, C21.2, C23.2, C25.2, C27.2, C28.2, C29.2, C30.2, C31.2, C32.2, C33.2, C34.2, C35.2, C36.2, C37.2, C38.2, C52.2, C54.2, C56.2, C58.2, J1.4, LED1.2 (GND), LED3.3 (GND), LED5.3 (GND), LED7.3 (GND), LED9.3 (GND), LED11.3 (GND), LED13.3 (GND), LED15.3 (GND), LED17.3 (GND), LED19.3 (GND), LED21.3 (GND), LED23.3 (GND), LED25.3 (GND), LED27.3 (GND), LED28.3 (GND), LED29.3 (GND), LED30.3 (GND), LED31.3 (GND), LED32.3 (GND), LED33.3 (GND), LED34.3 (GND), LED35.3 (GND), LED36.3 (GND), LED37.3 (GND), LED38.3 (GND), LED51.3 (GND), LED53.3 (GND), LED55.3 (GND), LED57.3 (GND), R3.2, SW57.C, TP2.1, U3.2, U5.3 (GND), U5.4 (GND), U5.5 (GND), U5.16 (GND); also elsewhere on the board
unnamed: D1.2 (A), SW1.2
unnamed: D3.2 (A), SW3.2
unnamed: D5.2 (A), SW5.2
unnamed: D7.2 (A), SW7.2
unnamed: D9.2 (A), SW9.2
unnamed: D11.2 (A), SW11.2
unnamed: D13.2 (A), SW13.2
unnamed: D14.2 (A), SW14.2
unnamed: D15.2 (A), SW15.2
unnamed: D16.2 (A), SW16.2
unnamed: D17.2 (A), SW17.2
unnamed: D18.2 (A), SW18.2
unnamed: D25.2 (A), SW25.2
unnamed: D26.2 (A), SW26.2
unnamed: D27.2 (A), SW27.2
unnamed: D28.2 (A), SW28.2
unnamed: D29.2 (A), SW29.2
unnamed: D30.2 (A), SW30.2
unnamed: D37.2 (A), SW37.2
unnamed: D38.2 (A), SW38.2
unnamed: D39.2 (A), SW39.2
unnamed: D40.2 (A), SW40.2
unnamed: D41.2 (A), SW41.2
unnamed: D42.2 (A), SW42.2
unnamed: D49.2 (A), SW49.2
unnamed: D50.2 (A), SW50.2
unnamed: D51.2 (A), SW51.2
unnamed: D52.2 (A), SW52.2
unnamed: D57.2 (A), SW57.S1
unnamed: LED1.3 (DI), R5.1
unnamed: LED3.4 (DIN), R7.1
unnamed: LED3.2 (DOUT), LED5.4 (DIN)
unnamed: LED5.2 (DOUT), LED7.4 (DIN)
unnamed: LED7.2 (DOUT), LED9.4 (DIN)
unnamed: LED9.2 (DOUT), LED11.4 (DIN)
unnamed: LED11.2 (DOUT), LED13.4 (DIN)
unnamed: LED13.2 (DOUT), LED15.4 (DIN)
unnamed: LED15.2 (DOUT), LED17.4 (DIN)
unnamed: LED17.2 (DOUT), LED19.4 (DIN)
unnamed: LED19.2 (DOUT), LED21.4 (DIN)
unnamed: LED21.2 (DOUT), LED23.4 (DIN)
unnamed: LED23.2 (DOUT), LED25.4 (DIN)
unnamed: LED25.2 (DOUT), LED27.4 (DIN)
unnamed: LED27.2 (DOUT), LED29.4 (DIN)
unnamed: LED28.4 (DIN), LED30.2 (DOUT)
unnamed: LED28.2 (DOUT), LED51.4 (DIN)
unnamed: LED29.2 (DOUT), LED31.4 (DIN)
unnamed: LED30.4 (DIN), LED32.2 (DOUT)
unnamed: LED31.2 (DOUT), LED33.4 (DIN)
unnamed: LED32.4 (DIN), LED34.2 (DOUT)
unnamed: LED33.2 (DOUT), LED35.4 (DIN)
unnamed: LED34.4 (DIN), LED36.2 (DOUT)
unnamed: LED35.2 (DOUT), LED37.4 (DIN)
unnamed: LED36.4 (DIN), LED38.2 (DOUT)
unnamed: LED37.2 (DOUT), LED38.4 (DIN)
unnamed: LED51.2 (DOUT), LED53.4 (DIN)
unnamed: LED53.2 (DOUT), LED55.4 (DIN)
unnamed: LED55.2 (DOUT), LED57.4 (DIN)

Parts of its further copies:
C2, C4, C6, C8, C10, C12, C14, C16, C18, C20, C22, C24, C26, C39, C40, C41, C42, C43, C44, C45, C46, C47, C48, C49, C50, C64, C66, C68, C70: 0.1uF; C_0603_1608Metric
D2, D4, D6, D8, D10, D12, D19, D20, D21, D22, D23, D24, D31, D32, D33, D34, D35, D36, D43, D44, D45, D46, D47, D48, D53, D54, D55, D56, D58: D; D_SOD-123
H2, H4, H6, H8: MountingHole; MountingHole_3.2mm_M3
J2: Conn_01x04_Socket; PinSocket_1x04_P2.54mm_Vertical
LED2: WS2812B-2020; LED-SMD_4P-L2.0-W2.0-TL_WS2812B-2020; LCSC Part C965555
LED4, LED6, LED8, LED10, LED12, LED14, LED16, LED18, LED20, LED22, LED24, LED26, LED39, LED40, LED41, LED42, LED43, LED44, LED45, LED46, LED47, LED48, LED49, LED50, LED63, LED65, LED67, LED69: SK6812MINI-E_C5149201; LED-SMD_L3.2-W2.8-LS5.9_SK6812MINI-E; LCSC Part C5149201
R2: 806K; R_0805_2012Metric
R4: 2M; R_0805_2012Metric
R6, R8: 330; R_0603_1608Metric
SW2, SW4, SW6, SW8, SW10, SW12, SW19, SW20, SW21, SW22, SW23, SW24, SW31, SW32, SW33, SW34, SW35, SW36, SW43, SW44, SW45, SW46, SW47, SW48, SW53, SW54, SW55, SW56: SW_Push; SW_choc_v1_HS_CPG135001S30_1u
SW58: RotaryEncoder_Switch; RotaryEncoder_Alps_EC11E-Switch_Vertical_H20mm
TP3: BAT; TestPoint_Pad_D2.0mm
TP4: GND; TestPoint_Pad_D2.0mm
U4: S2B-PH-K-S(LF)(SN); CONN-TH_S2B-PH-K-S-LF-SN; LCSC Part C173752
U6: nice!nano v2; NICE!NANO V2_2

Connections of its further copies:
/right/BT_PIN: R2.2, R4.1, U6.29 (P1.07)
/right/COL0: SW2.1, SW19.1, SW31.1, SW43.1, U6.6 (P0.17)
/right/COL1: SW4.1, SW20.1, SW32.1, SW44.1, SW58.S2, U6.7 (P0.20)
/right/COL2: SW6.1, SW21.1, SW33.1, SW45.1, SW53.1, U6.8 (P0.22)
/right/COL3: SW8.1, SW22.1, SW34.1, SW46.1, SW54.1, U6.9 (P0.24)
/right/COL4: SW10.1, SW23.1, SW35.1, SW47.1, SW55.1, U6.10 (P1.00)
/right/COL5: SW12.1, SW24.1, SW36.1, SW48.1, SW56.1, U6.11 (P0.11)
/right/Encoder_A: SW58.A, U6.24 (P1.11)
/right/Encoder_B: SW58.B, U6.25 (P0.10)
/right/LED: R8.2, U6.26 (P0.09)
/right/LED_STATUS: R6.2, U6.28 (P1.02)
/right/ROW0: D2.1 (K), D4.1 (K), D6.1 (K), D8.1 (K), D10.1 (K), D12.1 (K), U6.23 (P1.13)
/right/ROW1: D19.1 (K), D20.1 (K), D21.1 (K), D22.1 (K), D23.1 (K), D24.1 (K), U6.22 (P1.15)
/right/ROW2: D31.1 (K), D32.1 (K), D33.1 (K), D34.1 (K), D35.1 (K), D36.1 (K), U6.21 (P0.02)
/right/ROW3: D43.1 (K), D44.1 (K), D45.1 (K), D46.1 (K), D47.1 (K), D48.1 (K), U6.20 (P0.29)
/right/ROW4: D53.1 (K), D54.1 (K), D55.1 (K), D56.1 (K), D58.1 (K), U6.19 (P0.31)
/right/SCL: J2.2, U6.13 (P1.06)
/right/SDA: J2.1, U6.12 (P1.04)
/right/UART_RX: U6.1 (P0.06); also elsewhere on the board
/right/UART_TX: U6.2 (P0.08); also elsewhere on the board
/right/VBAT: R2.1, TP3.1, U4.1, U6.14 (BATIN), U6.15 (BATIN)
/right/VCC: C2.1, C4.1, C6.1, C8.1, C10.1, C12.1, C14.1, C16.1, C18.1, C20.1, C22.1, C24.1, C26.1, C39.1, C40.1, C41.1, C42.1, C43.1, C44.1, C45.1, C46.1, C47.1, C48.1, C49.1, C50.1, C64.1, C66.1, C68.1, C70.1, J2.3, LED2.4 (VDD), LED4.1 (VDD), LED6.1 (VDD), LED8.1 (VDD), LED10.1 (VDD), LED12.1 (VDD), LED14.1 (VDD), LED16.1 (VDD), LED18.1 (VDD), LED20.1 (VDD), LED22.1 (VDD), LED24.1 (VDD), LED26.1 (VDD), LED39.1 (VDD), LED40.1 (VDD), LED41.1 (VDD), LED42.1 (VDD), LED43.1 (VDD), LED44.1 (VDD), LED45.1 (VDD), LED46.1 (VDD), LED47.1 (VDD), LED48.1 (VDD), LED49.1 (VDD), LED50.1 (VDD), LED63.1 (VDD), LED65.1 (VDD), LED67.1 (VDD), LED69.1 (VDD), U6.18 (3.3v_Out); also elsewhere on the board
GND: C2.2, C4.2, C6.2, C8.2, C10.2, C12.2, C14.2, C16.2, C18.2, C20.2, C22.2, C24.2, C26.2, C39.2, C40.2, C41.2, C42.2, C43.2, C44.2, C45.2, C46.2, C47.2, C48.2, C49.2, C50.2, C64.2, C66.2, C68.2, C70.2, J2.4, LED2.2 (GND), LED4.3 (GND), LED6.3 (GND), LED8.3 (GND), LED10.3 (GND), LED12.3 (GND), LED14.3 (GND), LED16.3 (GND), LED18.3 (GND), LED20.3 (GND), LED22.3 (GND), LED24.3 (GND), LED26.3 (GND), LED39.3 (GND), LED40.3 (GND), LED41.3 (GND), LED42.3 (GND), LED43.3 (GND), LED44.3 (GND), LED45.3 (GND), LED46.3 (GND), LED47.3 (GND), LED48.3 (GND), LED49.3 (GND), LED50.3 (GND), LED63.3 (GND), LED65.3 (GND), LED67.3 (GND), LED69.3 (GND), R4.2, SW58.C, TP4.1, U4.2, U6.3 (GND), U6.4 (GND), U6.5 (GND), U6.16 (GND); also elsewhere on the board
unnamed: D2.2 (A), SW2.2
unnamed: D4.2 (A), SW4.2
unnamed: D6.2 (A), SW6.2
unnamed: D8.2 (A), SW8.2
unnamed: D10.2 (A), SW10.2
unnamed: D12.2 (A), SW12.2
unnamed: D19.2 (A), SW19.2
unnamed: D20.2 (A), SW20.2
unnamed: D21.2 (A), SW21.2
unnamed: D22.2 (A), SW22.2
unnamed: D23.2 (A), SW23.2
unnamed: D24.2 (A), SW24.2
unnamed: D31.2 (A), SW31.2
unnamed: D32.2 (A), SW32.2
unnamed: D33.2 (A), SW33.2
unnamed: D34.2 (A), SW34.2
unnamed: D35.2 (A), SW35.2
unnamed: D36.2 (A), SW36.2
unnamed: D43.2 (A), SW43.2
unnamed: D44.2 (A), SW44.2
unnamed: D45.2 (A), SW45.2
unnamed: D46.2 (A), SW46.2
unnamed: D47.2 (A), SW47.2
unnamed: D48.2 (A), SW48.2
unnamed: D53.2 (A), SW53.2
unnamed: D54.2 (A), SW54.2
unnamed: D55.2 (A), SW55.2
unnamed: D56.2 (A), SW56.2
unnamed: D58.2 (A), SW58.S1
unnamed: LED2.3 (DI), R6.1
unnamed: LED4.4 (DIN), R8.1
unnamed: LED4.2 (DOUT), LED6.4 (DIN)
unnamed: LED6.2 (DOUT), LED8.4 (DIN)
unnamed: LED8.2 (DOUT), LED10.4 (DIN)
unnamed: LED10.2 (DOUT), LED12.4 (DIN)
unnamed: LED12.2 (DOUT), LED14.4 (DIN)
unnamed: LED14.2 (DOUT), LED16.4 (DIN)
unnamed: LED16.2 (DOUT), LED18.4 (DIN)
unnamed: LED18.2 (DOUT), LED20.4 (DIN)
unnamed: LED20.2 (DOUT), LED22.4 (DIN)
unnamed: LED22.2 (DOUT), LED24.4 (DIN)
unnamed: LED24.2 (DOUT), LED26.4 (DIN)
unnamed: LED26.2 (DOUT), LED39.4 (DIN)
unnamed: LED39.2 (DOUT), LED41.4 (DIN)
unnamed: LED40.4 (DIN), LED42.2 (DOUT)
unnamed: LED40.2 (DOUT), LED63.4 (DIN)
unnamed: LED41.2 (DOUT), LED43.4 (DIN)
unnamed: LED42.4 (DIN), LED44.2 (DOUT)
unnamed: LED43.2 (DOUT), LED45.4 (DIN)
unnamed: LED44.4 (DIN), LED46.2 (DOUT)
unnamed: LED45.2 (DOUT), LED47.4 (DIN)
unnamed: LED46.4 (DIN), LED48.2 (DOUT)
unnamed: LED47.2 (DOUT), LED49.4 (DIN)
unnamed: LED48.4 (DIN), LED50.2 (DOUT)
unnamed: LED49.2 (DOUT), LED50.4 (DIN)
unnamed: LED63.2 (DOUT), LED65.4 (DIN)
unnamed: LED65.2 (DOUT), LED67.4 (DIN)
unnamed: LED67.2 (DOUT), LED69.4 (DIN)

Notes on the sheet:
OLED Screen
Nice!Nano V2
Battery Sense
Mounting Holes
Key Switches LED
Status RGB LED
Matrix
JST-PH 2 Pin Socket
Test Points

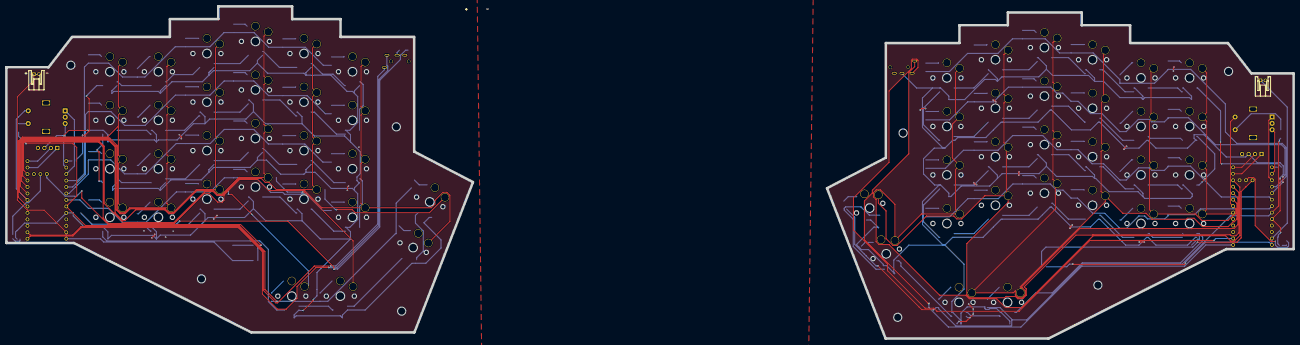
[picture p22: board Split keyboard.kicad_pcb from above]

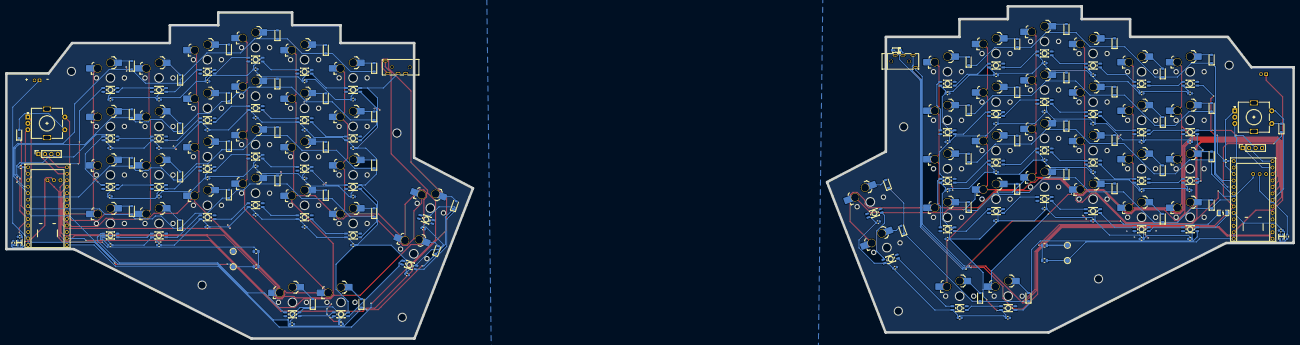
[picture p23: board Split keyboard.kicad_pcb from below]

Board: 2 copper layers, 505.4 x 130.4 mm, 262 parts (256 on the bottom side), 163 nets.

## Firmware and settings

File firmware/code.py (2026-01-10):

import board

from kmk.kmk_keyboard import KMKKeyboard
from kmk.scanners import DiodeOrientation
from kmk.keys import KC
from kmk.modules.split import Split, SplitType
from kmk.modules.encoder import EncoderHandler

keyboard = KMKKeyboard()

keyboard.col_pins = (
    board.P0_05,  
    board.P1_15, 
    board.P1_14,  
    board.P1_13,  
    board.P1_12,  
    board.P0_11,  
)

keyboard.row_pins = (
    board.P0_02,  
    board.P0_03,  
    board.P0_28,  
    board.P0_29,  
    board.P0_04,  
)

keyboard.diode_orientation = DiodeOrientation.ROW2COL

keyboard.modules.append(
    Split(
        split_type=SplitType.BLE,
        split_side=None,
    )
)

encoder = EncoderHandler()
encoder.pins = (
    (board.P0_06, board.P0_07, None),
)
encoder.map = [
    (KC.VOLD, KC.VOLU),
]
keyboard.modules.append(encoder)

keyboard.keymap = [
    [
        # ───── LEFT HALF ─────        ───── RIGHT HALF ─────
        KC.NO, KC.Q, KC.W, KC.E, KC.R, KC.T,    KC.Y, KC.U, KC.I, KC.O, KC.P, KC.NO,
        KC.NO, KC.A, KC.S, KC.D, KC.F, KC.G,    KC.H, KC.J, KC.K, KC.L, KC.SCLN, KC.NO,
        KC.NO, KC.Z, KC.X, KC.C, KC.V, KC.B,    KC.N, KC.M, KC.COMM, KC.DOT, KC.SLSH, KC.NO,
        KC.NO, KC.LCTL, KC.LALT, KC.LGUI, KC.SPC, KC.BSPC,
               KC.ENT, KC.SPC, KC.RGUI, KC.RALT, KC.RCTL, KC.NO,
        KC.TAB, KC.ESC, KC.NO, KC.NO, KC.NO, KC.NO,
               KC.NO, KC.NO, KC.NO, KC.NO, KC.NO, KC.NO,
    ]
]

keyboard.go()
